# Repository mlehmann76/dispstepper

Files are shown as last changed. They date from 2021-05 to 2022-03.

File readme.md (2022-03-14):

# Dispense steppermotor controller
control a steppermotor to dispense fluids from syringes

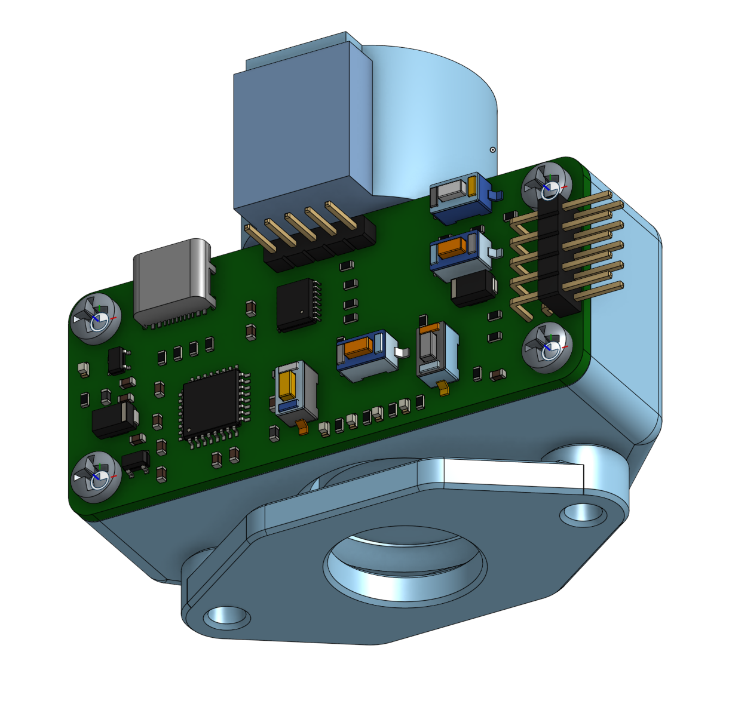
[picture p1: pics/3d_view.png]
3d view


4 modes

* Single Mode (dispensing on button, stop + retract after steps, selectable number of steps)
* Repeat Mode (continue dispense on pressed button, retract after button release, selectable number of steps)
* Manual Mode (control direction of stepper motor, selectable speed)
* External Mode (contro over usb serial device)

## Configuration
### By Button
push mode button, selected mode led will lit and settings can be changed by up/down button and led will switch to bar mode showning actual setting (0..3)
### By serial commands
all commands can change to read mode by adding a ?
| Command | Range | Description |
| :-- | :-- | :-- |
| *IDN | | read device version |
| SETup:FACtory:DEFault| 1 |set config to factory defaults |
| SETup:MODE | (0 .. 3) | get / set Mode / Single=0/Repeat=1/Manual=2/External=3 |
| SETup:SINGle:INDex |(0..3) | get / set single mode index |
| SETup:SINGle:VALue# |(0..4096)| get / set single mode value (# is 0..3)  steps |
| SETup:REPeat:INDex |(0..3)| get / set repeat mode index  |
| SETup:REPeat:VALue# |(0..4096)|get / set repeat mode value (# is 0..3) steps |
| SETup:MANual:INDex |(0..3)| get / set manual mode index  |
| SETup:MANual:VALue# |(0..1.0)| get / set manual mode value (# is 0..3) speed |
| SETup:EXTernal:SPeed |(0..1.0)| get / set speed value  for control over serial |
| SETup:EXTernal:STeps |(0..4096)| get / set steps value for control over serial |
| SETup:EXTernal:DIR |(-1, 0, 1)| get / set direction  for control over serial, this will start move if direction not 0. set to 0 after steps |
# Programming
## BootLoader
change into uf2-samdx1
> make BOARD=dispstepper jlink-flash
* now LED D2 should blink
## Application
### via uf2 bootloader
* double tap reset to enter boot loader
* led2 will start blinking
* the board will register as a mass storage device
* put the uf2 update file onto the mass storage and firware update will start

# License
See Microchip / Atmel / Arm source code files for license.

The new code is licensed under MIT.

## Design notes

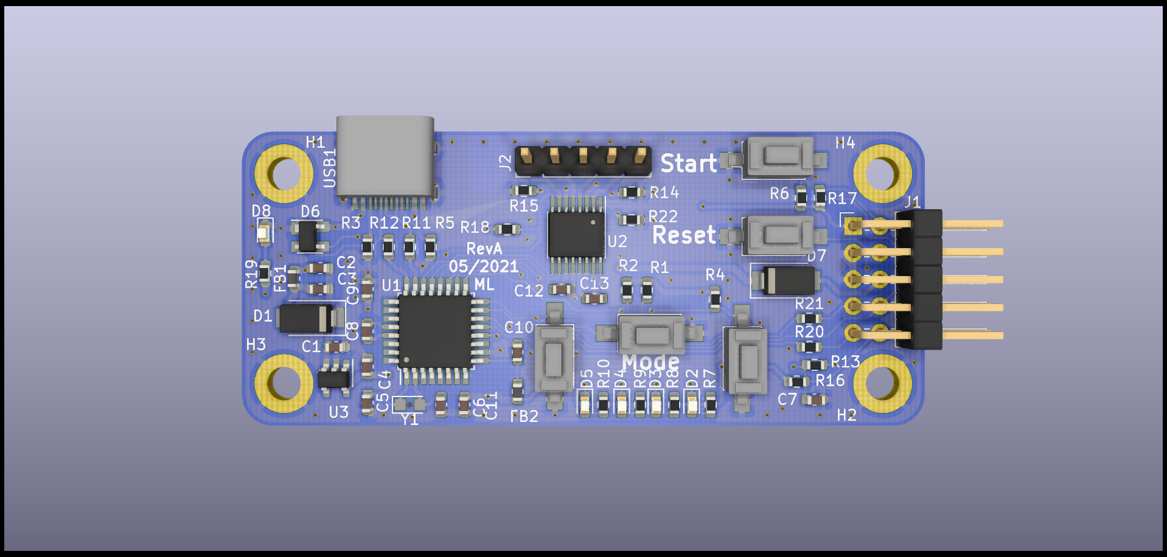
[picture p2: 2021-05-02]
hardware/reva/reva_top.png

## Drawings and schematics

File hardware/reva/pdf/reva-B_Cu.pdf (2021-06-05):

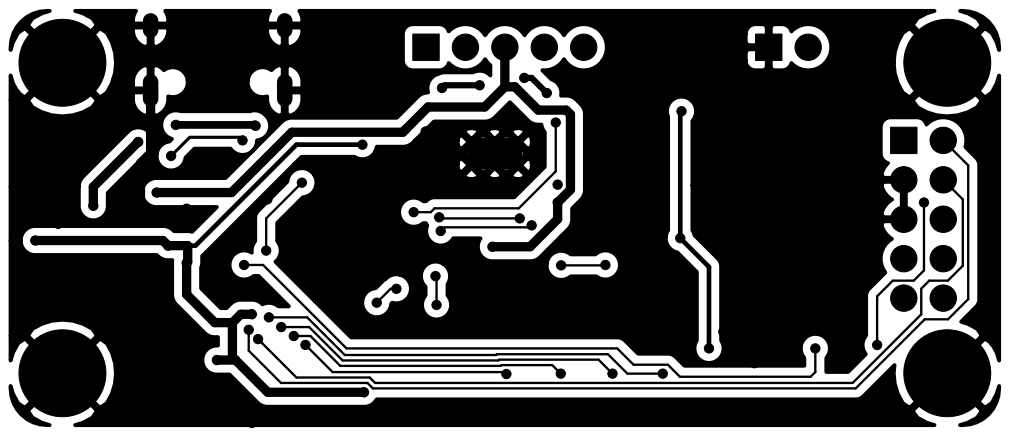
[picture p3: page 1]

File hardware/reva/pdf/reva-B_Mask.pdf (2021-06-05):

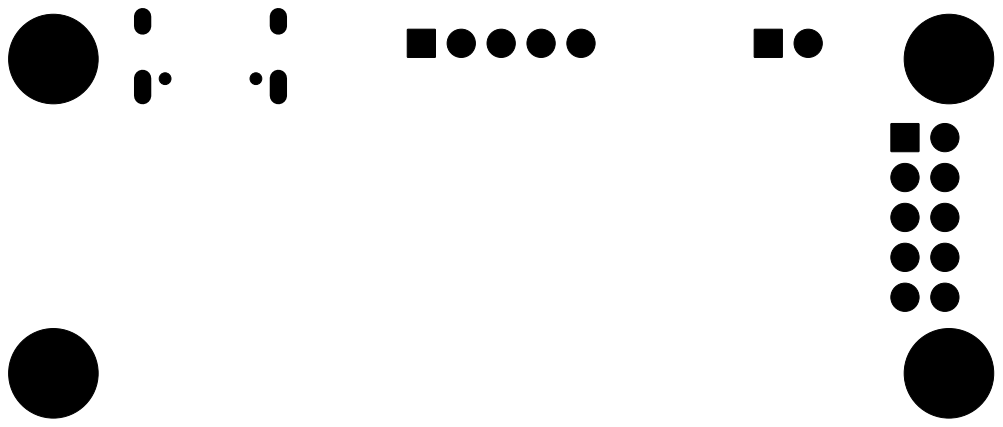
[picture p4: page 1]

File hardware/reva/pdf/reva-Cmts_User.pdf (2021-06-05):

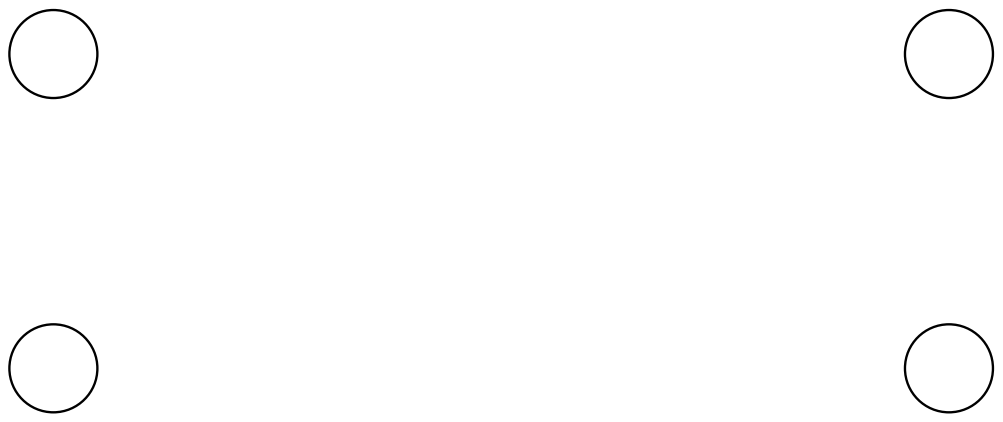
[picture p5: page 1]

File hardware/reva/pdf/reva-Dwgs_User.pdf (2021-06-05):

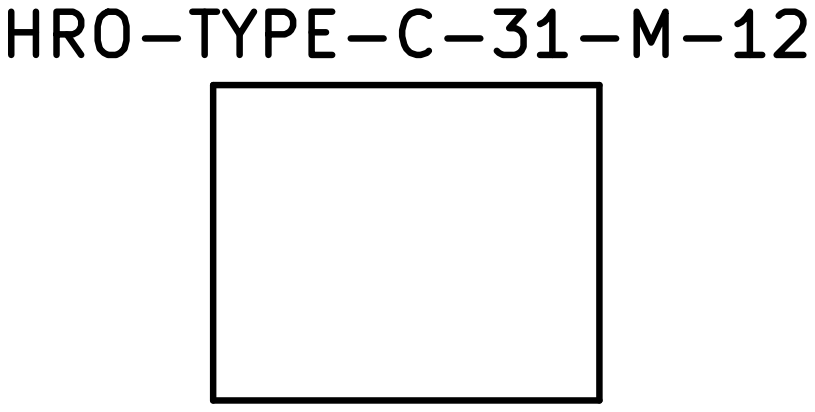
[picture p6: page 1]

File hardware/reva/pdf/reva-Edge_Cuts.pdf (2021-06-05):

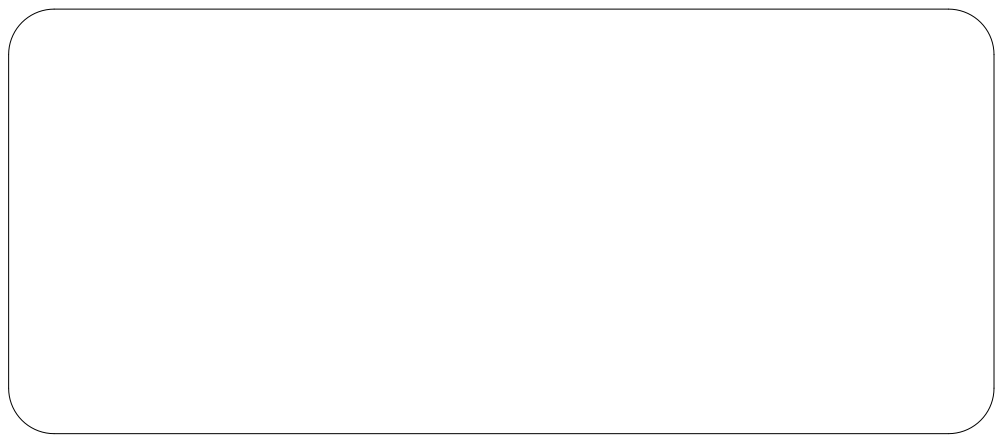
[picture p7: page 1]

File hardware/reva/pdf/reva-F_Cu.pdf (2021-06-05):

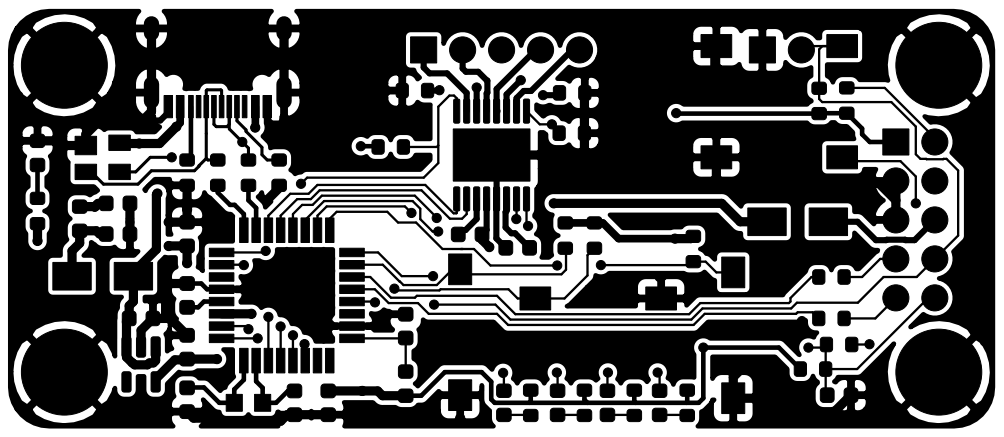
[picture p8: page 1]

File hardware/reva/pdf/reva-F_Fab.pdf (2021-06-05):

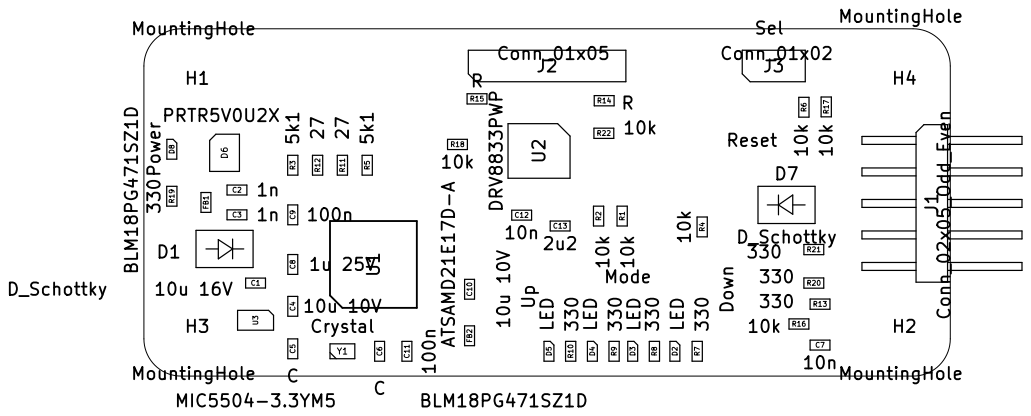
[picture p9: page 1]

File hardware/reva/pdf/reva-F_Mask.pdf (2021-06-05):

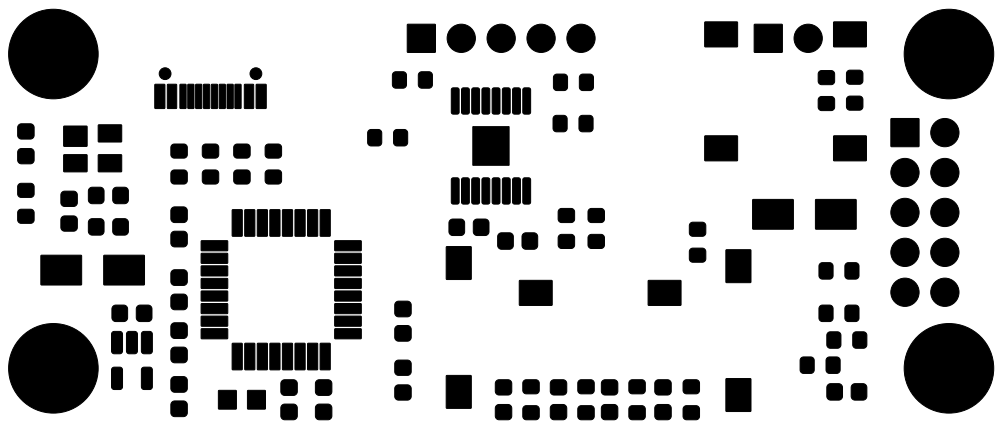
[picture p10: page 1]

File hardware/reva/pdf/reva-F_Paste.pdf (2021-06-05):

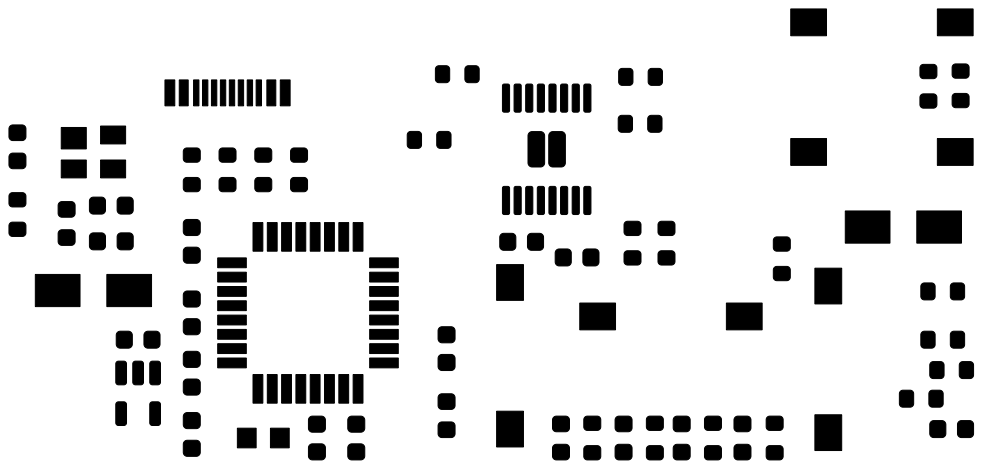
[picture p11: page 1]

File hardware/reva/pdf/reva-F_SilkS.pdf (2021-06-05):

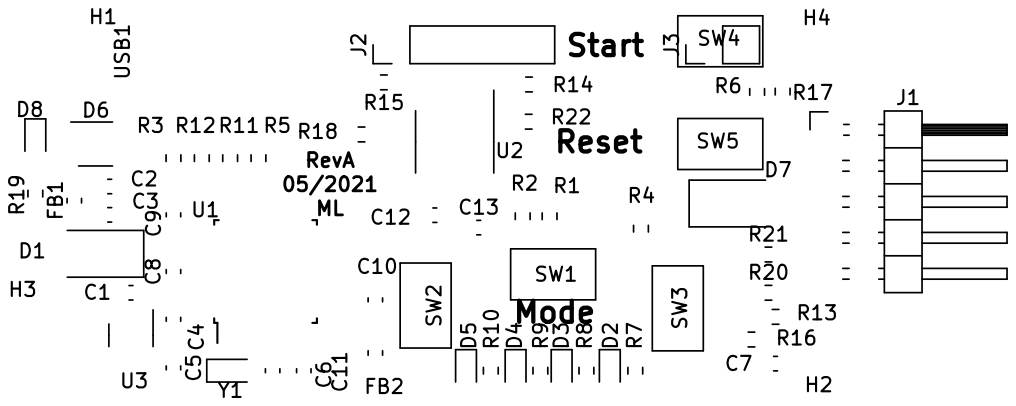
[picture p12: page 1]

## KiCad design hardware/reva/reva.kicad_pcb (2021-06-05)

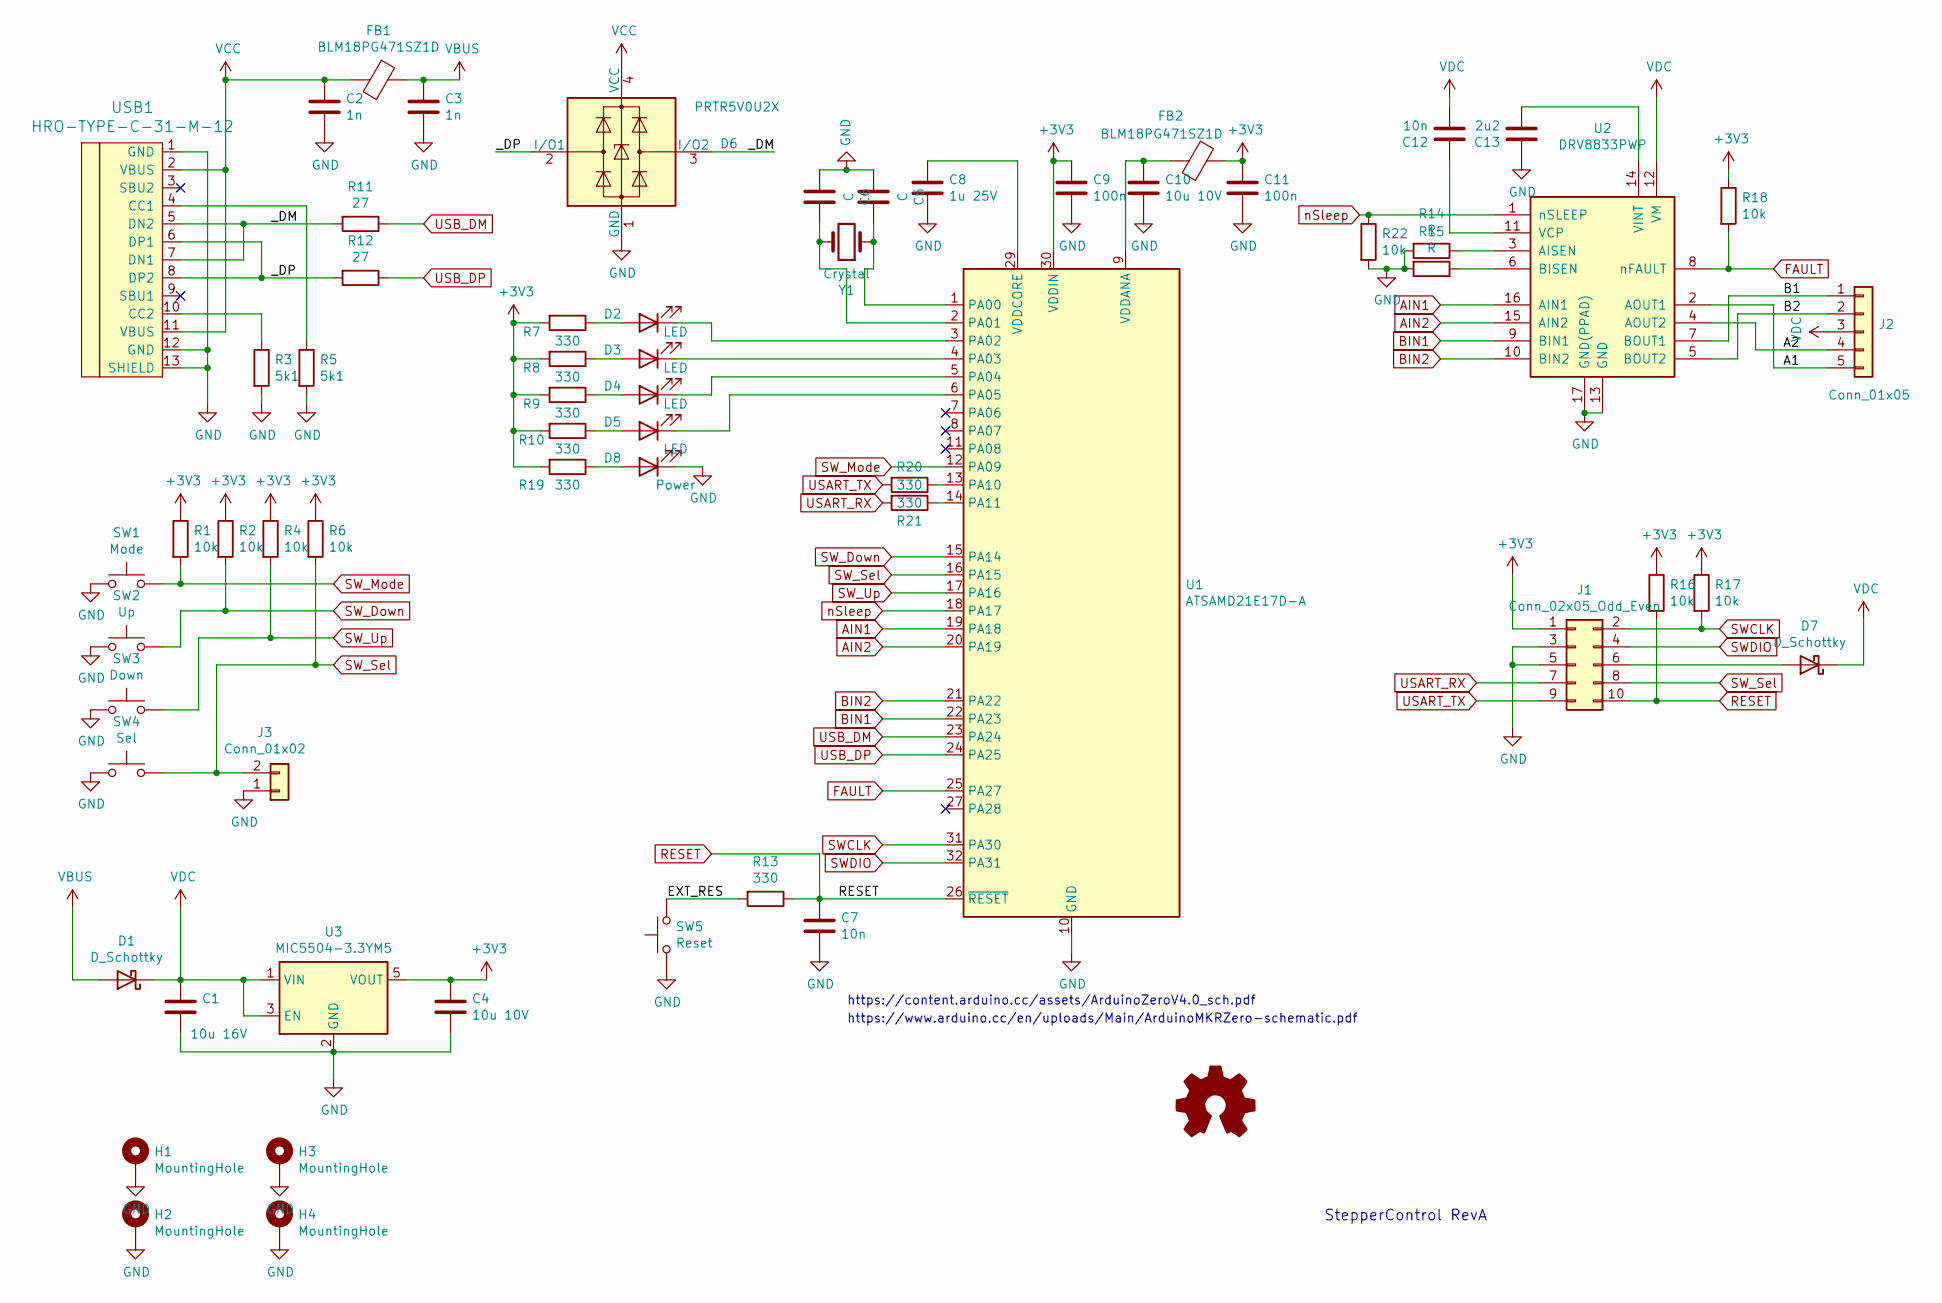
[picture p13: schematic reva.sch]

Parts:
C1: 10u 16V; C_0603_1608Metric
C2, C3: 1n; C_0603_1608Metric
C4, C10: 10u 10V; C_0603_1608Metric
C5, C6: C; C_0603_1608Metric
C7, C12: 10n; C_0603_1608Metric
C8: 1u 25V; C_0603_1608Metric
C9, C11: 100n; C_0603_1608Metric
C13: 2u2; C_0603_1608Metric
D1, D7: D_Schottky; D_SMA
D2, D3, D4, D5: LED; LED_0603_1608Metric
D6: PRTR5V0U2X; SOT-143
D8: Power; LED_0603_1608Metric
FB1, FB2: BLM18PG471SZ1D; L_0603_1608Metric
H1, H2, H3, H4: MountingHole; MountingHole_3.2mm_M3_DIN965_Pad
J1: Conn_02x05_Odd_Even; PinHeader_2x05_P2.54mm_Horizontal
J2: Conn_01x05; PinHeader_1x05_P2.54mm_Vertical
J3: Conn_01x02; PinHeader_1x02_P2.54mm_Vertical
R1, R2, R4, R6, R16, R17, R18, R22: 10k; R_0603_1608Metric
R3, R5: 5k1; R_0603_1608Metric
R7, R8, R9, R10, R13, R19, R20, R21: 330; R_0603_1608Metric
R11, R12: 27; R_0603_1608Metric
R14, R15: R; R_0603_1608Metric
SW1: Mode; PTS636_SMT_G
SW2: Up; PTS636_SMT_G
SW3: Down; PTS636_SMT_G
SW4: Sel; PTS636_SMT_G
SW5: Reset; PTS636_SMT_G
U1: ATSAMD21E17D-A; TQFP-32_7x7mm_P0.8mm
U2: DRV8833PWP; HTSSOP-16-1EP_4.4x5mm_P0.65mm_EP3.4x5mm_Mask2.46x2.31mm_The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
U3: MIC5504-3.3YM5; SOT-23-5
USB1: HRO-TYPE-C-31-M-12
Y1: Crystal; Crystal_SMD_2012-2Pin_2.0x1.2mm_HandSoldering

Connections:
+3V3: C4.1, C9.1, C11.1, FB2.1, J1.1, R1.1, R2.1, R4.1, R6.1, R7.2, R8.2, R9.2, R10.2, R16.1, R17.1, R18.1, R19.2, U1.30 (VDDIN), U3.5 (VOUT)
/A1: J2.5, U2.2 (AOUT1)
/A2: J2.4, U2.4 (AOUT2)
/B1: J2.1, U2.7 (BOUT1)
/B2: J2.2, U2.5 (BOUT2)
/EXT_RES: R13.2, SW5.2
/_DM: D6.3 (I/O2), R11.2, USB1.5 (DN2), USB1.7 (DN1)
/_DP: D6.2 (I/O1), R12.2, USB1.6 (DP1), USB1.8 (DP2)
AIN1: U1.19 (PA18), U2.16 (AIN1)
AIN2: U1.20 (PA19), U2.15 (AIN2)
BIN1: U1.22 (PA23), U2.9 (BIN1)
BIN2: U1.21 (PA22), U2.10 (BIN2)
FAULT: R18.2, U1.25 (PA27), U2.8 (nFAULT)
GND: C1.2, C2.2, C3.2, C4.2, C5.2, C6.2, C7.2, C8.2, C9.2, C10.2, C11.2, C13.1, D6.1 (GND), D8.1 (K), H1.1, H2.1, H3.1, H4.1, J1.3, J1.5, J3.1, R3.2, R5.2, R14.2, R15.2, R22.2, SW1.1, SW2.1, SW3.1, SW4.1, SW5.1, U1.10 (GND), U1.28 (GND), U2.13 (GND), U2.17 (GND(PPAD)), U3.2 (GND), USB1.1 (GND), USB1.12 (GND), USB1.13 (SHIELD)
unnamed: C5.1, U1.1 (PA00), Y1.1
unnamed: C6.1, U1.2 (PA01), Y1.2
unnamed: C8.1, U1.29 (VDDCORE)
unnamed: C10.1, FB2.2, U1.9 (VDDANA)
unnamed: C12.1, U2.11 (VCP)
unnamed: C13.2, U2.14 (VINT)
unnamed: D2.1 (K), U1.3 (PA02)
unnamed: D2.2 (A), R7.1
unnamed: D3.1 (K), U1.4 (PA03)
unnamed: D3.2 (A), R8.1
unnamed: D4.1 (K), U1.5 (PA04)
unnamed: D4.2 (A), R9.1
unnamed: D5.1 (K), U1.6 (PA05)
unnamed: D5.2 (A), R10.1
unnamed: D7.2 (A), J1.6
unnamed: D8.2 (A), R19.1
unnamed: R3.1, USB1.10 (CC2)
unnamed: R5.1, USB1.4 (CC1)
unnamed: R14.1, U2.3 (AISEN)
unnamed: R15.1, U2.6 (BISEN)
unnamed: R20.1, U1.13 (PA10)
unnamed: R21.1, U1.14 (PA11)
RESET: C7.1, J1.10, R13.1, R16.2, U1.26 (~RESET)
SWCLK: J1.2, R17.2, U1.31 (PA30)
SWDIO: J1.4, U1.32 (PA31)
SW_Down: R2.2, SW2.2, U1.15 (PA14)
SW_Mode: R1.2, SW1.2, U1.12 (PA09)
SW_Sel: J1.8, J3.2, R6.2, SW4.2, U1.16 (PA15)
SW_Up: R4.2, SW3.2, U1.17 (PA16)
USART_RX: J1.7, R21.2
USART_TX: J1.9, R20.2
USB_DM: R11.1, U1.23 (PA24)
USB_DP: R12.1, U1.24 (PA25)
VBUS: C3.1, D1.2 (A), FB1.1
VCC: C2.1, D6.4 (VCC), FB1.2, USB1.2 (VBUS), USB1.11 (VBUS)
VDC: C1.1, C12.2, D1.1 (K), D7.1 (K), J2.3, U2.12 (VM), U3.1 (VIN), U3.3 (EN)
nSleep: R22.1, U1.18 (PA17), U2.1 (nSLEEP)

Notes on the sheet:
https://content.arduino.cc/assets/ArduinoZeroV4.0_sch.pdf
https://www.arduino.cc/en/uploads/Main/ArduinoMKRZero-schematic.pdf
StepperControl RevA

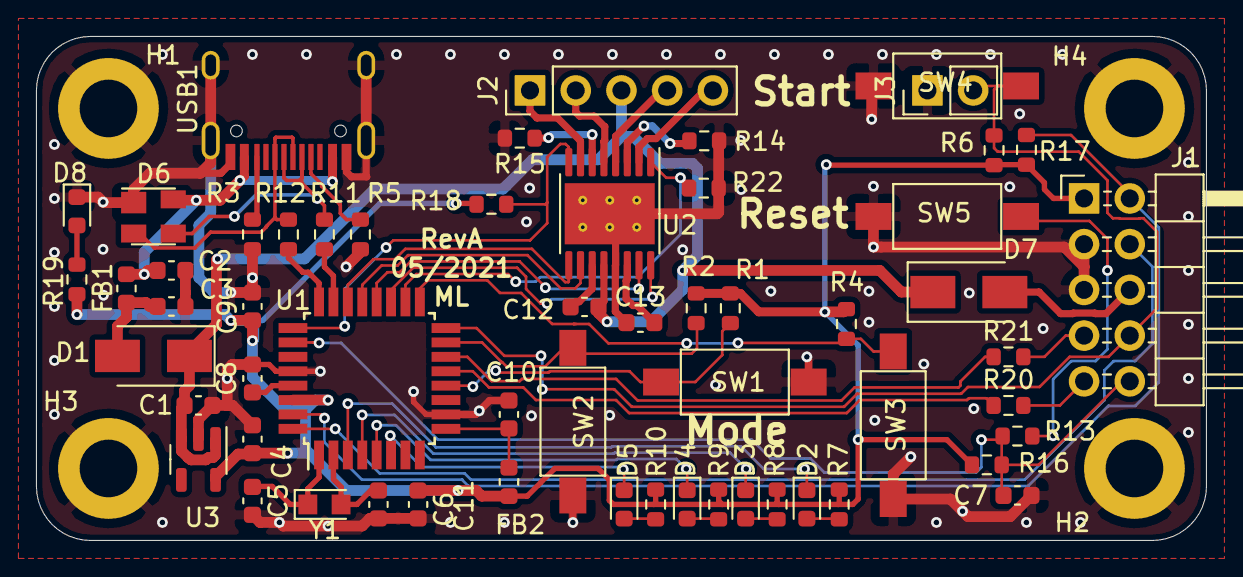
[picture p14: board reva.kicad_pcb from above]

Board: 2 copper layers, 65.0 x 28.0 mm, 62 parts (0 on the bottom side), 51 nets.

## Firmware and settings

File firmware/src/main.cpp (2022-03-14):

#include "board.h"
#include "cmdparse.h"
#include "config.h"
#include "control.h"
#include "leds.h"
#include "mode.h"
#include "simpleparser.h"
#include "stepper.h"
#include "usb_cdc.h"
#include "user_board.h"
#include <atmel_start.h>
#include <stdint.h>

using buttonCheckType = buttonCheck<uint8_t, SW_MODE, SW_DOWN, SW_SEL, SW_UP>;
using ledViewType = ledview<uint8_t, LED5, LED4, LED3, LED2>;
using modeType = mode<uint8_t, buttonCheckType, ledViewType>;

using namespace std::placeholders;

int main(void) {
  /* Initializes MCU, drivers and middleware */
  atmel_start_init();
  SysTick_Init(48e6);

  Config config;
  usb_cdc_wrapper cdc;
  CmdParse parser = {config, cdc};
  stepCtrl step = {4096, 3e6};
  modeType mode(&config);
  control ctrl = {&config, &step};
  mode.registerModeCb(std::bind(&control::onModeChange, &ctrl, _1, _2));
  mode.registerButtonCb(
      std::bind(&control::onButtonChange<uint8_t>, &ctrl, _1, _2));
  gpio_set_pin_level(nSLEEP, 1);

  while (1) {
    //
    config.run(getTick());
    mode.run(getTick());
    ctrl.run();
    step.func(hri_tccount16_read_COUNT_reg(TC3));
    //
    parser.service();
  }
}

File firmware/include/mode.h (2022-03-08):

#ifndef __MODE_H_
#define __MODE_H_

#include "board.h"
#include "config.h"
#include "inplace_function.h"
#include "leds.h"
#include "user_board.h"
#include <cstdint>

template <typename TGpio, typename buttonCheckType, typename ledViewType>
class mode {
public:
  using modeCbType = stdext::inplace_function<void(viewMode, uint32_t)>;
  using buttonCbType = stdext::inplace_function<void(TGpio, bool)>;

  struct modeselect {
    void select(uint32_t tick) {
      isEnabled = true;
      count = tick;
    }
    bool isTimeOut(uint32_t tick) const { return tick > count; }
    //
    bool isEnabled;
    uint32_t count;
  };

public:
  constexpr mode(Config *_c)
      : m_button{}, m_led{}, m_mode(_c->get<Config::IDX_Mode>()),
        m_config(_c), m_modeSelect{true, 0},
        m_modeIndex{_c->get<Config::IDX_ModeSingleIdx>(),
                    _c->get<Config::IDX_ModeRepeatIdx>(),
                    _c->get<Config::IDX_ModeManualIdx>(),
                    _c->get<Config::IDX_ModeExternIdx>()} {}
  //
  void run(uint32_t tick);
  //
  void checkbuttons();
  //
  void registerModeCb(modeCbType &&cb) { m_modeChangeCb = cb; }
  void registerButtonCb(buttonCbType &&cb) { m_buttonChangeCb = cb; }
  //
  uint32_t modeValue() const { return m_modeIndex[m_mode]; }

private:
  void onModeButton(uint32_t tick);
  //
  void onUpDownButton(uint32_t tick);
  //
  void checkConfig(uint32_t tick);
  //
  void updateConfig();
  //
  void updateLed(bool forceBar = false) {
    if (m_modeSelect.isEnabled && forceBar == false) {
      m_led.set(m_mode, single{});
    } else {
      m_led.set(m_modeIndex[m_mode], bar{});
    }
  }
  //
  uint32_t modeMin() const;
  uint32_t modeMax() const;
  //
  buttonCheckType m_button;
  ledViewType m_led;
  viewMode m_mode;
  Config *m_config;
  modeselect m_modeSelect;
  uint32_t m_modeIndex[MODES];
  modeCbType m_modeChangeCb;
  buttonCbType m_buttonChangeCb;
};
/*
 *
 */
template <typename TGpio, typename buttonCheckType, typename ledViewType>
void mode<TGpio, buttonCheckType, ledViewType>::run(uint32_t tick) {
  //
  m_button.run(tick);
  //
  if (m_modeSelect.isEnabled) {
    onModeButton(tick);
    onUpDownButton(tick);
    if (m_modeSelect.isTimeOut(tick)) {
      m_modeSelect.isEnabled = false;
      updateLed();
      updateConfig();
      if (m_modeChangeCb) {
        m_modeChangeCb(m_mode, modeValue());
      }
    }
  } else if (m_button.stateChanged(SW_MODE) && m_button.pressed(SW_MODE)) {
    m_modeSelect.select(tick + TIMEOUT);
    updateLed();
  } else {
    checkbuttons();
    //
    checkConfig(tick);
  }
}
/*
 *
 */
template <typename TGpio, typename buttonCheckType, typename ledViewType>
void mode<TGpio, buttonCheckType, ledViewType>::checkbuttons() {
  constexpr static TGpio buttons[] = {SW_UP, SW_DOWN, SW_SEL};
  if (m_buttonChangeCb) {
    for (auto b : buttons) {
      if (m_button.stateChanged(b)) {
        m_buttonChangeCb(b, m_button.state(b) == buttonCheckType::bpressed);
      }
    }
  }
}
/*
 *
 */
template <typename TGpio, typename buttonCheckType, typename ledViewType>
void mode<TGpio, buttonCheckType, ledViewType>::onModeButton(uint32_t tick) {
  if (m_button.stateChanged(SW_MODE) && m_button.pressed(SW_MODE)) {
    switch (m_mode) {
    case ModeSingle:
      m_mode = ModeRepeat;
      break;
    case ModeRepeat:
      m_mode = ModeManual;
      break;
    case ModeManual:
      m_mode = ModeExtern;
      break;
    case ModeExtern:
      m_mode = ModeSingle;
      break;
    };
    m_modeSelect.select(tick + TIMEOUT);
    updateLed();
  }
}
/*
 *
 */
template <typename TGpio, typename buttonCheckType, typename ledViewType>
void mode<TGpio, buttonCheckType, ledViewType>::onUpDownButton(uint32_t tick) {
  if (m_button.stateChanged(SW_UP) && m_button.pressed(SW_UP) &&
      m_modeIndex[m_mode] < modeMax()) {
    m_modeIndex[m_mode]++;
    updateLed(true);
    m_modeSelect.select(tick + TIMEOUT);
  }
  if (m_button.stateChanged(SW_DOWN) && m_button.pressed(SW_DOWN) &&
      m_modeIndex[m_mode] > modeMin()) {
    m_modeIndex[m_mode]--;
    updateLed(true);
    m_modeSelect.select(tick + TIMEOUT);
  }
}
/*
 *
 */
template <typename TGpio, typename buttonCheckType, typename ledViewType>
void mode<TGpio, buttonCheckType, ledViewType>::checkConfig(uint32_t tick) {
  bool update = false;
  if (m_config->get<Config::IDX_Mode>() != m_mode) {
    m_mode = m_config->get<Config::IDX_Mode>();
    m_modeSelect.select(tick + TIMEOUT);
    update = true;
  }
  if (m_modeIndex[ModeSingle] != m_config->get<Config::IDX_ModeSingleIdx>()) {
    m_modeIndex[ModeSingle] = m_config->get<Config::IDX_ModeSingleIdx>();
    update = true;
  }
  if (m_modeIndex[ModeRepeat] != m_config->get<Config::IDX_ModeRepeatIdx>()) {
    m_modeIndex[ModeRepeat] = m_config->get<Config::IDX_ModeRepeatIdx>();
    update = true;
  }
  if (m_modeIndex[ModeManual] != m_config->get<Config::IDX_ModeManualIdx>()) {
    m_modeIndex[ModeManual] = m_config->get<Config::IDX_ModeManualIdx>();
    update = true;
  }
  if (m_modeIndex[ModeExtern] != m_config->get<Config::IDX_ModeExternIdx>()) {
    m_modeIndex[ModeExtern] = m_config->get<Config::IDX_ModeExternIdx>();
    update = true;
  }
  if (update) {
    updateLed();
  }
}
/*
 *
 */
template <typename TGpio, typename buttonCheckType, typename ledViewType>
void mode<TGpio, buttonCheckType, ledViewType>::updateConfig() {
  switch (m_mode) {
  case ModeRepeat:
    m_config->set<Config::IDX_ModeRepeatIdx>(m_modeIndex[m_mode]);
    break;
  case ModeSingle:
    m_config->set<Config::IDX_ModeSingleIdx>(m_modeIndex[m_mode]);
    break;
  case ModeManual:
    m_config->set<Config::IDX_ModeManualIdx>(m_modeIndex[m_mode]);
    break;
  case ModeExtern:
    m_config->set<Config::IDX_ModeExternIdx>(m_modeIndex[m_mode]);
    break;
  }
  m_config->set<Config::IDX_Mode>(m_mode);
}
/*
 *
 */
template <typename TGpio, typename buttonCheckType, typename ledViewType>
uint32_t mode<TGpio, buttonCheckType, ledViewType>::modeMin() const {
  switch (m_mode) {
  case ModeSingle:
    return rmin<Config::IDX_ModeSingleIdx>();
  case ModeRepeat:
    return rmin<Config::IDX_ModeRepeatIdx>();
  case ModeManual:
    return rmin<Config::IDX_ModeManualIdx>();
  case ModeExtern:
    return rmin<Config::IDX_ModeExternIdx>();
  }
  return 0;
}
/*
 *
 */
template <typename TGpio, typename buttonCheckType, typename ledViewType>
uint32_t mode<TGpio, buttonCheckType, ledViewType>::modeMax() const {
  switch (m_mode) {
  case ModeSingle:
    return rmax<Config::IDX_ModeSingleIdx>();
  case ModeRepeat:
    return rmax<Config::IDX_ModeRepeatIdx>();
  case ModeManual:
    return rmax<Config::IDX_ModeManualIdx>();
  case ModeExtern:
    return rmax<Config::IDX_ModeExternIdx>();
  }
  return 0;
}
#endif // __MODE_H_

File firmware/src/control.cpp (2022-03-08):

#include "control.h"
#include "config.h"
#include "stepper.h"

control::control(Config *_c, stepCtrl *_s)
    : m_config(_c), m_stepper(_s), sstate(SIDLE), m_lastButton(-1),
      m_lastButtonState(false), m_lastDir(DIR_NONE) {}
//
void control::run() {
  switch (mode()) {
  case ModeRepeat:
  case ModeSingle:
    onModeSingleRepeat();
    break;
  case ModeManual:
    onModeManual();
    break;
  case ModeExtern:
    onModeExtern();
  }
}
//
float control::modeValue() const {
  switch (mode()) {
  case ModeRepeat:
    switch (m_config->get<Config::IDX_ModeRepeatIdx>()) {
    case 0:
      return m_config->get<Config::IDX_ModeRepeat0>();
    case 1:
      return m_config->get<Config::IDX_ModeRepeat1>();
    case 2:
      return m_config->get<Config::IDX_ModeRepeat2>();
    case 3:
      return m_config->get<Config::IDX_ModeRepeat3>();
    }
    //
    break;
  case ModeSingle:
    switch (m_config->get<Config::IDX_ModeSingleIdx>()) {
    case 0:
      return m_config->get<Config::IDX_ModeSingle0>();
    case 1:
      return m_config->get<Config::IDX_ModeSingle1>();
    case 2:
      return m_config->get<Config::IDX_ModeSingle2>();
    case 3:
      return m_config->get<Config::IDX_ModeSingle3>();
    }
    break;
  case ModeManual:
    switch (m_config->get<Config::IDX_ModeManualIdx>()) {
    case 0:
      return m_config->get<Config::IDX_ModeManual0>();
    case 1:
      return m_config->get<Config::IDX_ModeManual1>();
    case 2:
      return m_config->get<Config::IDX_ModeManual2>();
    case 3:
      return m_config->get<Config::IDX_ModeManual3>();
    }
    break;
  case ModeExtern:
    return 0; // not handled here
  }
  return 0;
}
//
void control::onModeChange(viewMode m, uint32_t v) {
  sstate = SIDLE;
  m_stepper->cw(0.0, 0);
}
//
template <> void control::onButtonChange(uint8_t b, bool s) {
  m_lastButton = b;
  m_lastButtonState = s;
}
//
void control::onModeSingleRepeat() {
  switch (sstate) {
  case SIDLE:
    if (m_lastButton == SW_SEL && m_lastButtonState == true) {
      m_stepper->cw(SPEED, modeValue());
      m_lastButton = -1;
      sstate = SDIRCW;
    }
    break;

  case SDIRCW:
  case SDIRCCW:
    if (m_lastButton == SW_SEL && m_lastButtonState == false) {
      m_lastButton = -1;
      sstate = SRUN;
      break;
    }
    if (mode() == ModeRepeat && !m_stepper->isRunning()) {
      m_stepper->cw(SPEED, modeValue());
    }
    break;

  case SRUN:
    if (!m_stepper->isRunning()) {
      if (m_stepper->dir() == stepCtrl::CW) {
        m_stepper->ccw(SPEED, modeValue() / 16);
      } else {
        m_stepper->cw(SPEED, modeValue() / 16);
      }
      sstate = SRETRACT;
    }
    break;

  case SRETRACT:
    if (!m_stepper->isRunning()) {
      sstate = SIDLE;
      break;
    }
  }
}
//
void control::onModeManual() {
  switch (sstate) {
  case SIDLE:
    if (m_lastButton == SW_UP && m_lastButtonState == true) {
      m_stepper->cw(modeValue(), BUTTON_STEPS);
      m_lastButton = -1;
      sstate = SDIRCW;
    } else if (m_lastButton == SW_DOWN && m_lastButtonState == true) {
      m_stepper->ccw(modeValue(), BUTTON_STEPS);
      m_lastButton = -1;
      sstate = SDIRCCW;
    }
    break;

  case SDIRCW:
    if (m_lastButton == SW_UP && m_lastButtonState == false) {
      m_lastButton = -1;
      sstate = SRUN;
      break;
    }
    if (!m_stepper->isRunning()) {
      m_stepper->cw(modeValue(), BUTTON_STEPS);
    }
    break;

  case SDIRCCW:
    if (m_lastButton == SW_DOWN && m_lastButtonState == false) {
      m_lastButton = -1;
      sstate = SRUN;
      break;
    }
    if (!m_stepper->isRunning()) {
      m_stepper->ccw(modeValue(), BUTTON_STEPS);
    }
    break;

  case SRUN:
    if (m_stepper->dir() == stepCtrl::CW) {
      m_stepper->ccw(modeValue(), BUTTON_STEPS / 16);
    } else {
      m_stepper->cw(modeValue(), BUTTON_STEPS / 16);
    }
    sstate = SRETRACT;
    break;

  case SRETRACT:
    if (!m_stepper->isRunning()) {
      sstate = SIDLE;
      break;
    }
  }
}
//
void control::onModeExtern() {
  if (m_config->get<Config::IDX_ModeExternDIR>() != m_lastDir) {
    m_lastDir = m_config->get<Config::IDX_ModeExternDIR>();
    switch (m_config->get<Config::IDX_ModeExternDIR>()) {
    case DIR_CCW:
      m_stepper->ccw(m_config->get<Config::IDX_ModeExternSPD>(),
                     m_config->get<Config::IDX_ModeExternSTEPS>());
      break;
    case DIR_CW:
      m_stepper->cw(m_config->get<Config::IDX_ModeExternSPD>(),
                    m_config->get<Config::IDX_ModeExternSTEPS>());
      break;
    case DIR_NONE:
      m_stepper->cw(0.0, 0);
      break;
    }
  }
  if (!m_stepper->isRunning() &&
      m_config->get<Config::IDX_ModeExternDIR>() != DIR_NONE) {
    m_config->set<Config::IDX_ModeExternDIR>(DIR_NONE);
  }
}

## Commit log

2021-04-28 schema update
    [reva.sch]
2021-04-29 pcb placement
    [reva.kicad_pcb, reva.sch]
2021-05-02 layout final
    [reva.kicad_pcb]
2021-05-02 added con for Sel, added gerber
    [reva-B_Cu.gbr, reva-B_Mask.gbr, reva-B_Paste.gbr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]
2021-06-05 hardware update
    [reva-B_Cu.gbl, reva-B_Cu.gbr, reva-B_Mask.gbr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]
2021-06-07 add led and mode handling
2021-07-09 fixed button handling and timer
    [control.cpp, main.cpp, mode.h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]
2021-08-16 added mode/led update after config change
2021-08-18 update to use latest tool chain 10.3-2021.07
2021-08-19 switch build target to minsizerel
2022-03-08 fixed config, fixed simpleparser, added control over usb, added readme
    [reva.sch]
